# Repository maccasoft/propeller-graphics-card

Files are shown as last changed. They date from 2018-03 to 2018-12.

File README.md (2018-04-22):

## Propeller Graphics Card

Add-on board and firmware designed for the [RC2014](http://rc2014.co.uk/) computer to provide graphics capabilities.

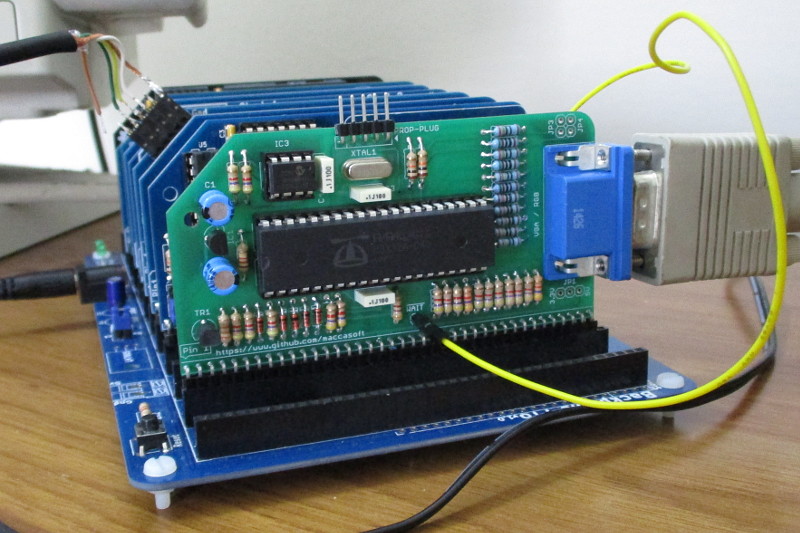
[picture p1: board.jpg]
The board


### Specifications

 * Resolution up to 320x240 pixels with 64 colors
 * Tile graphics with 8x8 pixels tiles
 * Sprites with 8x8 up to 32x32 pixels
 * Full screen scroll
 * Overlays for score and indicators
 * Bitmap graphics modes 320x240x3bpp, 256x192x4bpp and 256x224x4bpp
 * RGB PAL, NTSC and VGA output

The board uses I/O ports **40H, 41H, 42H and 43H** for programming.

See the [Wiki](https://github.com/maccasoft/propeller-graphics-card/wiki) pages for the documentation.

### Schematic

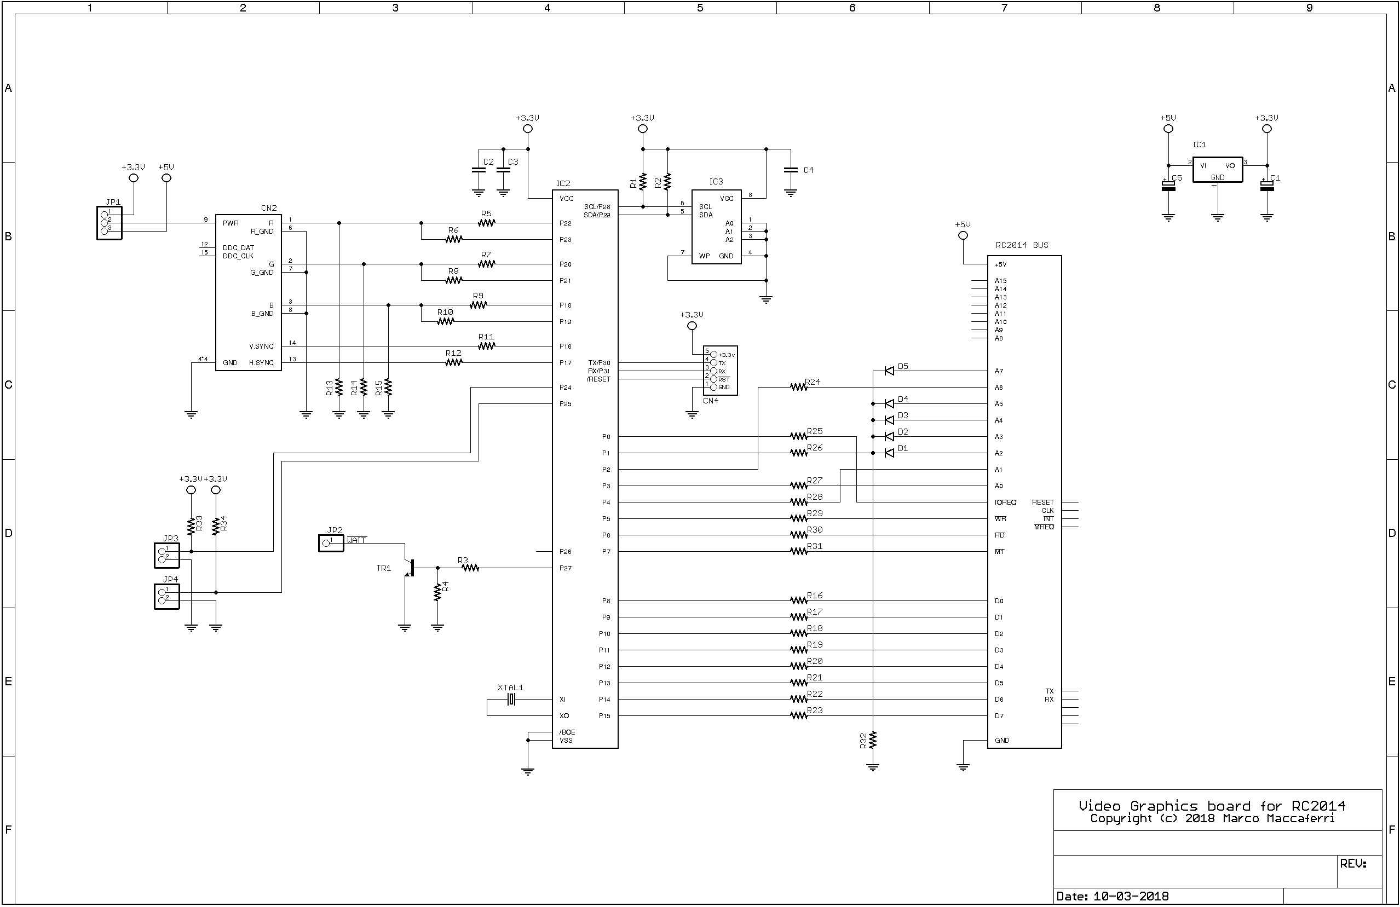
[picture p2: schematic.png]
The schematic


| Parts List | | | |
| --- | --- | --- | --- |
| R1, R2, R16-R31 | 4.700 ohm 1/4 watt  | IC1 | MCP1700-3302E/TO |
| R3 | 1.200 ohm 1/4 watt  | IC2 | P8X32A-D40 |
| R4 | 33.000 ohm 1/4 watt | IC3 | 24LC512 |
| R5, R7, R9 | 510 ohm 1/4 watt 1% | TR1 | NPN Transistor BC547 |
| R6, R8, R10, R11, R12 | 240 ohm 1/4 watt 1% | JP1 | 3 pin male header |
| R13, R14, R15 | 130 ohm 1/4 watt 1% | JP2 | 1 pin male header |
| R32, R33, R34 | 10.000 ohm 1/4 watt | JP3, JP4 | 2 pin male header |
| C1, C5 | 10 uF 63v elettr. | CN1 | 40 pin male header, right angle |
| C2, C3, C4 | 100.000 pF poly. | CN2 | DB15 HD female connector |
| D1, D2, D3, D4, D5 | 1N4148 | CN4 | 5 pin male header |
| XTAL1 | 5 MHz crystal | | |

Board shared on [OSHPark](https://oshpark.com/shared_projects/1gud4wQD) and available on [Tindie](https://www.tindie.com/stores/maccasoft/).

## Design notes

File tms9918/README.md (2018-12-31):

## TMS9918 Emulation Firmware

The TMS9918A was used in the TI-99/4A, MSX, ColecoVision and original Sega SG-1000.
This emulation firmware supports all graphics modes (mode 1, mode 2, multicolor mode) and the 40x24 text mode.

The emulation tries to be compatible with the original chip as much as possible however due to how
the Propeller operates there are some differences:

 * Wait states are automatically added by asserting the WAIT line. Unlike the original chip there is
   no need to add NOP instructions to delay writes.
 * Interrupts are not currently supported. To implement frame synchronization use the Frame flag readed from
   the status register. Alternatively, any OUT instruction to the port 43H will halt the processor until
   the next frame blanking period.
 * Collision flag and 5th sprite number doesn't yet work.
 * Palette colors may appear different compared to the original chip due to the different DAC configurations.
 * Emulation is not cycle perfect. Registers are readed at the beginning of each rendered line, however the
   timings are not comparable with the original chip and graphic tricks may not work as expected.
 * Undocumented modes are not supported.

The firmware maps the board's I/O ports as follows:

 *  **40H** - TMS9918 data port  
 *  **41H** - TMS9918 registers / address setup port  
 *  **42H** - Reserved  
 *  **43H** - Frame synchronization  

See here for a board to use the original chip with the RC2014 computer:  
[https://github.com/jblang/TMS9918A](https://github.com/jblang/TMS9918A)

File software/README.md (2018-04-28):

## Propeller Graphics Card

Utilities and demo programs designed to run from CP/M.

 * **fwupd.com**  
   Firmware update utility.  
   
 * **hscroll.com**  
   Horizontal scroll with music demo.  
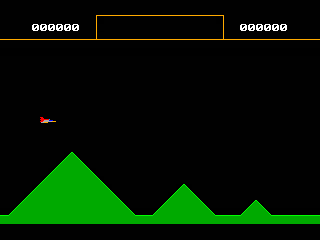
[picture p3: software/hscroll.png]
     
 * **vscroll.com**  
   Vertical scroll with music demo.  
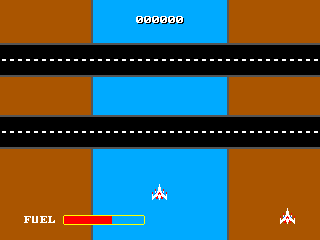
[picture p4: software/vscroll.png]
     
   
 * **bars.com**  
   Colored bars.  
 * **sinwave.com**  
   Simple 3D math function drawing using the Z-buffer algorithm (from z88dk).  
 * **coswave.com**  
   Simple 3D math function drawing using the Z-buffer algorithm (from z88dk).  

All programs can be compiled with [z88dk](https://www.z88dk.org) using the provided Makefile or individually using the instructions in the source files.

### License

Unless otherwise specified all programs are distributed with the GNU GPL-V3 license, images, design files and other artwork
are distributed under the Creative Commons Attribution-ShareAlike 3.0 license.

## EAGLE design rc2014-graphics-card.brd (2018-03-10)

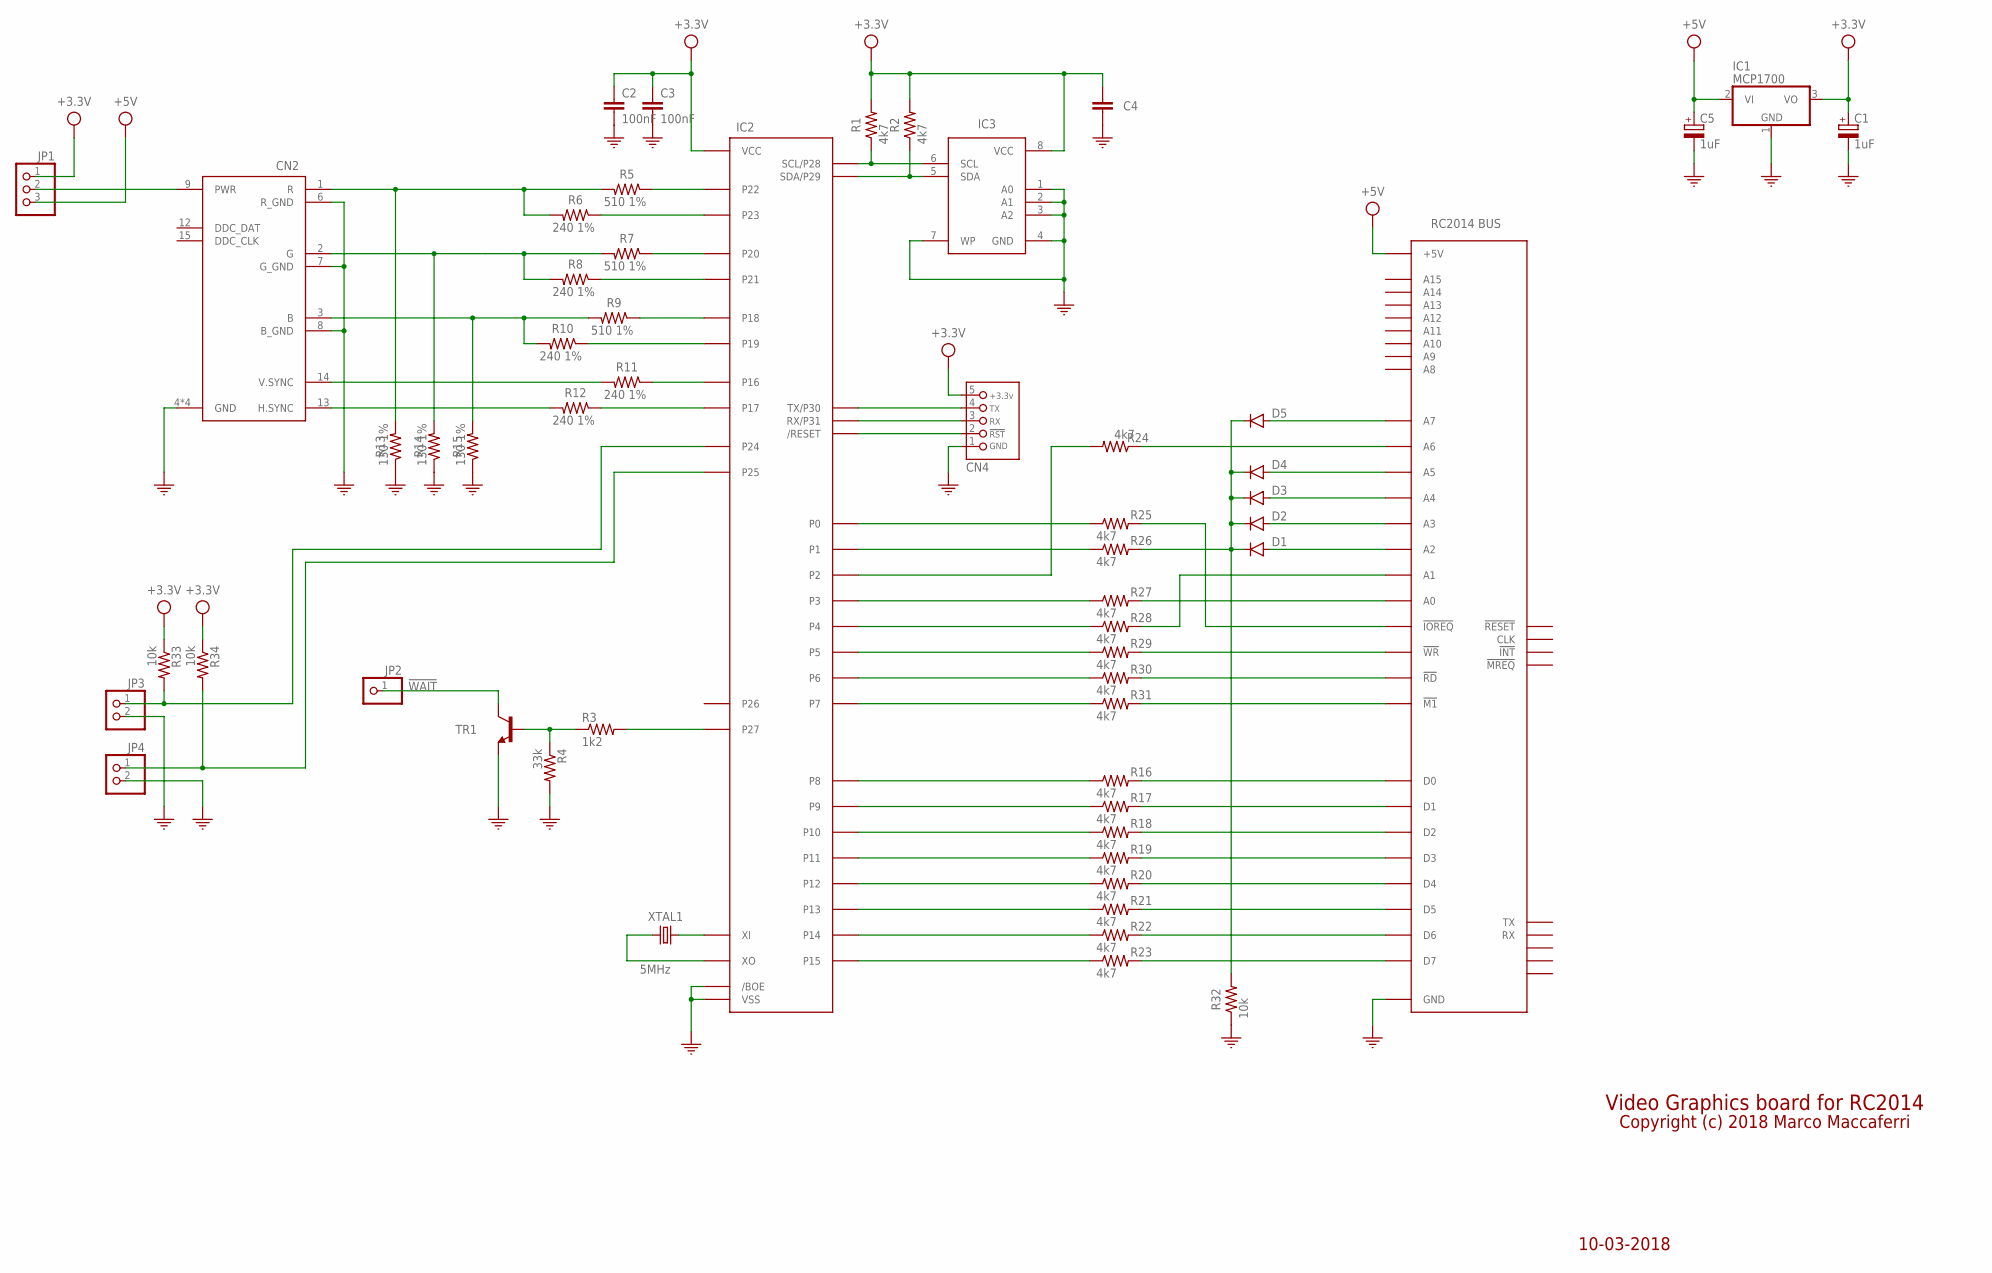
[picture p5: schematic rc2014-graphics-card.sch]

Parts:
C1, C5: 1uF; E2,5-6; MPN ESK105M050AC3AA
C2, C3, C4: 100nF; C050-025X075; MPN R82EC3100AA70J
CN1: RC2014BUS; MPN PRPC040SBAN-M71RC
CN2: VGA; MPN 1734344-1
CN4: PROPELLER_ICSP_HEADER; HEADER_PRG_1X05; MPN PRPC005SAAN-RC
D1, D2, D3, D4, D5: 1N4148DO35-7; DO35-7
IC1: MCP1700; TO92; MPN MCP1700-3302E/TO
IC2: P8X32A-B-D40; DIL40; MPN P8X32A-D40
IC3: 24LC512-I/P; DIL08; MPN 24LC256-I/P
JP1: PINHD-1X3; 1X03
JP2: PINHD-1X1; 1X01
JP3, JP4: PINHD-1X2; 1X02
R1, R2: 4k7; 0207/10; MPN CFR-25JB-52-4K7
R3: 1k2; 0207/10
R4: 33k; 0204/7
R5, R7, R9: 510 1%; 0207/10; MPN RNMF14FTC510R
R6, R8, R10, R11, R12: 240 1%; 0207/10; MPN RNMF14FTC240R
R13, R14, R15: 130 1%; 0207/10; MPN RNMF14FTC130R
R16, R17, R18, R19, R20, R21, R22, R23, R24, R25, R26, R27, R28, R29, R30, R31: 4k7; 0204/7
R32: 10k; 0204/7
R33, R34: 10k; 0207/10
TR1: BC547A; TO92
XTAL1: 5MHz; HC49/S; MPN ECS-50-20-4X

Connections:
!IOREQ!: IC2.1 (P0), R25.1
!M1!: IC2.8 (P7), R31.1
!RD!: IC2.7 (P6), R30.1
!WAIT!: JP2.1, TR1.1 (C)
!WR!: IC2.6 (P5), R29.1
+3.3V: C1.+, C2.1, C3.1, C4.1, CN4.5, IC1.3 (VO), IC2.12 (VCC), IC2.32 (VCC), IC3.8 (VCC), JP1.1, R1.2, R2.2, R33.1, R34.1
+5V: C5.+, CN1.+5V, IC1.2 (VI), JP1.3
A0: IC2.4 (P3), R27.1
A1: IC2.5 (P4), R28.1
A6: IC2.3 (P2), R24.2
ADDR: IC2.2 (P1), R26.1
B: CN2.3 (B), R9.2, R10.2, R15.2
D0: IC2.13 (P8), R16.1
D1: IC2.14 (P9), R17.1
D2: IC2.15 (P10), R18.1
D3: IC2.16 (P11), R19.1
D4: IC2.17 (P12), R20.1
D5: IC2.18 (P13), R21.1
D6: IC2.19 (P14), R22.1
D7: IC2.20 (P15), R23.1
G: CN2.2 (G), R7.2, R8.2, R14.2
GND: C1.-, C2.2, C3.2, C4.2, C5.-, CN1.GND, CN2.4 (GND), CN2.5 (GND), CN2.6 (R_GND), CN2.7 (G_GND), CN2.8 (B_GND), CN2.10 (GND), CN2.11 (GND), CN4.1, IC1.1 (GND), IC2.9 (VSS), IC2.10 (/BOE), IC2.29 (VSS), IC3.1 (A0), IC3.2 (A1), IC3.3 (A2), IC3.4 (GND), IC3.7 (WP), JP3.2, JP4.2, R4.2, R13.1, R14.1, R15.1, R32.1, TR1.3 (E)
GPU_SCL: IC2.37 (SCL/P28), IC3.6 (SCL), R1.1
GPU_SDA: IC2.38 (SDA/P29), IC3.5 (SDA), R2.1
HSYNC: CN2.13 (H.SYNC), R12.2
unnamed: IC2.30 (XI), XTAL1.1
unnamed: IC2.31 (XO), XTAL1.2
unnamed: CN1.D3, R19.2
unnamed: CN1.D2, R18.2
unnamed: CN1.D1, R17.2
unnamed: CN1.D0, R16.2
unnamed: CN1.D4, R20.2
unnamed: CN1.D5, R21.2
unnamed: CN1.D6, R22.2
unnamed: CN1.D7, R23.2
unnamed: CN4.2, IC2.11 (/RESET)
unnamed: CN4.3, IC2.40 (RX/P31)
unnamed: CN4.4, IC2.39 (TX/P30)
unnamed: CN1.A3, D2.A
unnamed: CN1.A4, D3.A
unnamed: CN1.A5, D4.A
unnamed: CN1.A6, R24.1
unnamed: CN1.A7, D5.A
unnamed: D1.C, D2.C, D3.C, D4.C, D5.C, R26.2, R32.2
unnamed: CN1.A2, D1.A
unnamed: CN1.A1, R28.2
unnamed: CN1.A0, R27.2
unnamed: CN1.!RD!, R30.2
unnamed: CN1.!WR!, R29.2
unnamed: CN1.!M1!, R31.2
unnamed: CN1.!IOREQ!, R25.2
unnamed: CN2.9 (PWR), JP1.2
unnamed: R3.1, R4.1, TR1.2 (B)
unnamed: IC2.36 (P27), R3.2
unnamed: IC2.33 (P24), JP3.1, R33.2
unnamed: IC2.34 (P25), JP4.1, R34.2
P16: IC2.21 (P16), R11.1
P17: IC2.22 (P17), R12.1
P18: IC2.23 (P18), R9.1
P19: IC2.24 (P19), R10.1
P20: IC2.25 (P20), R7.1
P21: IC2.26 (P21), R8.1
P22: IC2.27 (P22), R5.1
P23: IC2.28 (P23), R6.1
R: CN2.1 (R), R5.2, R6.2, R13.2
VSYNC: CN2.14 (V.SYNC), R11.2

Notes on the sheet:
RC2014 BUS
Video Graphics board for RC2014
10-03-2018
Copyright (c) 2018 Marco Maccaferri

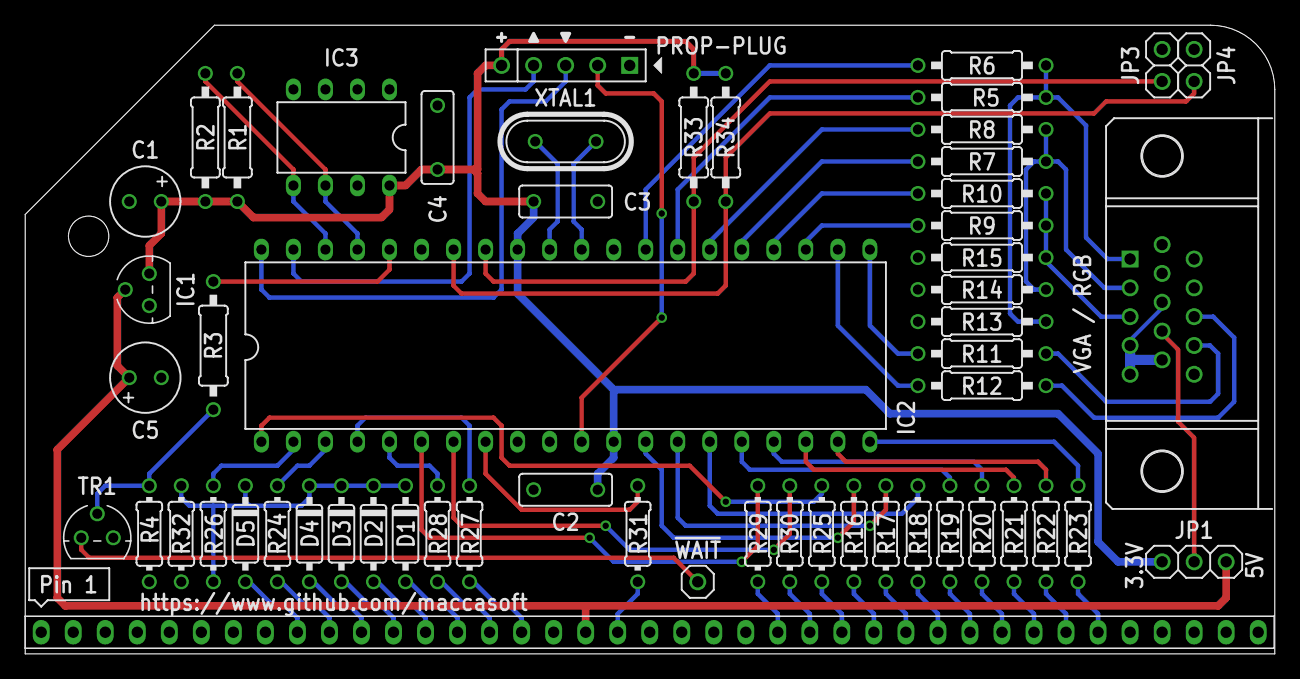
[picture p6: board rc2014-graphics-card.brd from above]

Board: 2 copper layers, 99.1 x 49.9 mm, 56 parts (0 on the bottom side), 66 nets.

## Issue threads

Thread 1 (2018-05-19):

Does it require Backplane Pro or any backplane?

sajattack, 2018-05-19:

maccasoft, 2018-05-19:
The connector is the standard single-row compatible with any backplane, however to have frame synchronization a wire must be connected to the Z80 WAIT line (the yellow cable in the photo) on the extended bus connector, if available, or on the CPU board.

Closed 2018-05-19.

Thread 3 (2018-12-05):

full 9x16 support now available

konimaru, 2018-12-05:
Just to let you know that there is now a new version available which uses a real 9x16 font (liberated from some FON file). The colour blink attribute is currently MIA but can be brought back if necessary.

konimaru, 2018-12-07:
(optional) blink mode is now available again.

maccasoft, 2018-12-07:
Thanks, I'm following your repository and saw the discussion. I haven't yet tested the new driver, will do soon.
Thank you very much for your work!

konimaru, 2018-12-18:
In case you didn't notice, there is now another version using an 8x16 font but with characters $C0-$DF having their 8th column duplicated (like IBM's MDA mode). Will save you 1K of hub RAM. Otherwise it's the same as the **NINE**.

**Also, happy holidays from Lake Constance (the one in Germany) and best wishes for 2019!**

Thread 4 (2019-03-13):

How fast can it go?

cbmeeks, 2019-03-13:
I've wondered about using a Propeller in a SBC that I have created.  My computer runs between 1 and 4 MHz (6502).  I have pushed it to 8 MHz with no issues.

However, I've wondered how the Propeller could keep up at higher speeds?  I imagine RC2014's usually run at 3.5 - 4.0 MHz.

So my question is, how fast have you pushed this card using direct bus access?  When do you think the CPU would have to have wait states before the Propeller can't handle it?

Thanks

maccasoft, 2019-03-13:
The RC2014 standard clock is 7.3728 MHz and there aren't problems with the Propeller. However the Z80 adds a wait state to all I/O operations that helps with the timings.

I haven't run many speed tests, however there are two things to consider:

1. Write operations (OUT instructions). The limit is about the time needed to store the data bus value after the port address condition is met, then you can use the time needed by the processor to read and decode other instructions to do all internal things. I think that the Z80 can be pushed to 10-12 MHz without problems, then it is just a matter of how many things the Propeller needs to do before being ready for the next I/O data. The fastest I/O instruction on the Z80 is OUTI which takes 16 clock cycles, plenty of time to write to the Propeller hub ram.

2. Read operations (IN instructions). This absolutely needs wait states, there is simply not enough time to toggle the port bits so the Z80 can read the correct data. Maybe at 2MHz or less it can work, haven't tried that slow.

The standard firmware for the graphics card uses write-only operations without wait states unless the user wants to change resolution, in that case the wait line is asserted until the Propeller is ready again. The TMS9918 emulation firmware on the other hand always uses wait states because it allows to read and write to the vram.

cbmeeks, 2019-03-13:
Thanks for the response.

The 6502, IIRC, is around 4-7 clock cycles for a write operation.  I guess I just need to do the math.  Right now, I'm running at 1 MHz while I develop.  So probably more than OK there in read or write.

Thanks for your input.

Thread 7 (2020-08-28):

Combine with VT100 functionality

cyrusbuilt, 2020-08-28:
This is really more of a technical question than an "issue":

Looking at the schematics for both the graphics card and the vt100 terminal card, it looks like it would be relatively easy to combine the functionality of both cards into one, at least from an electrical point of view.  Also, if designed to be compatible with the enhanced RC2014 bus or perhaps the unofficial BP-80 bus (such as that used by Stephen Cousins SC126, which is backward-compatible) it could tie the /WAIT pin straight into the bus as opposed to having a separate header pin for it.

But then there is the firmware.  My first thought is you could send a command to switch between graphics mode and terminal mode. The board would start up in terminal mode by default, of course.  Then a game or program that required graphics would send a command to enter graphics mode and before the program exited, it would have to restore terminal mode.

But I have no idea if that is something that is technically possible on the propeller in terms of firmware size or memory usage, etc.

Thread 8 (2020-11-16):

How can i test this board

almajiro, 2020-11-16:
I finished solder this board. so i want to test it.
I burned the firmware to eeprom using tools from P8X Game System download page.

but, the board is doesn't work.
/WAIT signal is going to low immediately.

Then i burned the VT100 Emulator firmware and it works.

What are the possible causes?

Thank you.

maccasoft, 2020-11-16:
Try to load the TMS9918 emulation firmware and run the ASCII.ASM code, this is the only example that doesn't require the WAIT line support.

almajiro, 2020-11-17:
thank you for your reply.

I burned the TMS firmware then I assembled ascii.asm using tasm on dosbox.
and tested with J.B. Langston's z80ctrl board.

but It didn't work.

I'm using 24LC256 instead of 24LC512. Can this be the cause?

maccasoft, 2020-11-17:
I don't know how z80ctrl board works and if it has conflicts with this board, try to use the minimum required standard boards to test these issue, otherwise we can't know where the problem is.
The TMS9918 demo programs are meant to run from the standard monitor at address 5000h, so set the rom to load the standard monitor, upload the hex file produced by the compiler and run with G5000. Remove the WAIT line wire if this causes problems, for the ASCII demo it is not required.
The 24LC256 should work without problems, the current firmware is below the 32k limit.

almajiro, 2020-11-17:
I tested it with the SCM monitor program, but it didn't work. (i changed the .org to 8000 from 5000)

Does the TMS mode firmware output a VGA signal after the power is turned on?

maccasoft, 2020-11-21:
Yes, all firmwares outputs the VGA signal.
Have you checked the board for shorts and bad solders ?

almajiro, 2020-11-23:
I checked the all connection via multimeter.

maccasoft, 2020-11-26:
I have verified the firmware, both the release and the latest source, and both works as expected with the demo code.

If the VT100 emulator firmware works, at least the VGA connections looks working (both boards are using the same pins for VGA output, because of that you should always get a VGA signal from all firmwares), however the similarity stops here. Another difference is that this firmware doesn't display a blinking cursor only a blank screen (monitors should tell you if there is an active signal).

If the wait line is always asserted (and removing the jumper wire allows the Z80 to boot) makes me think that something is wrong with the VGA initialization but I can't think of a reason for that. I have used a stand-alone programmer (TL866) to write the firmware to the eeprom.

Other things to check are the diodes orientation (the black band should be on the upper side, near the Propeller chip), the transistor TR1 should be the correct type and with the correct pin disposition. I can't think of anything else.

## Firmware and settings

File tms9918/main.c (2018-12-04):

/*
 * Propeller Graphics Card for RC2014 Computer
 *
 * Copyright (c) 2018 Marco Maccaferri
 * MIT Licensed
 *
 */

#include <stdint.h>
#include <propeller.h>

extern uint32_t _load_start_cog_uart_driver[];
extern uint32_t _load_start_cog_bus_interface[];

int main()
{
    // starts the bus interface code replacing the current cog
    coginit(cogid(), _load_start_cog_bus_interface, 0);

    return 0;
}

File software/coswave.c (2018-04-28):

/*

	Z88DK base graphics libraries examples
	Simple 3D math function drawing using the Z-buffer algorithm
	
	The picture size is automatically adapted to the target display size
	
	to build:  zcc +<target> <stdio options> -lm -create-app sinwave.c
	
	Examples:
	  zcc +zx -lm -lndos -create-app sinwave.c
	  zcc +aquarius -lm -create-app sinwave.c
	
	$Id: coswave.c,v 1.4 2011-04-01 06:50:45 stefano Exp $

*/

#pragma output noprotectmsdos
#pragma output noredir
#pragma output nogfxglobals

#include <graphics.h>
#include <stdio.h>
#include <math.h>

#define PORTC       0x40
#define PORTD       0x41

#define SETMODE     0x00
#define SETPIX      0x01
#define CLRSCR      0x09
#define WRPAL       0x0B
#define WRBMP       0x0D

#define MODE_320240 0x03
#define MODE_256192 0x04
#define MODE_256224 0x05

#define getmaxx()   255
#define getmaxy()   191

void clg()
{
    outp(PORTC, SETMODE);
    outp(PORTD, MODE_256192);
    outp(PORTD, 0x00);
    outp(PORTD, 0x00);

    outp(PORTC, SETPIX);
}

void plot(int x, int y)
{
    if (x >= 0 && x <= getmaxx() && y >= 0 && y <= getmaxy()) {
        outp(PORTD, y);
        outp(PORTD, x);
        outp(PORTD, 15);
    }
}

void main()
{
    float x,y,incr,yenlarge;
    int z,buf;

	clg();
	incr=2.0/(float)getmaxx();
	yenlarge=(float)getmaxy() / 6.0;

	for (x=-3.0; x<0; x=x+incr)
	{
		buf=255;
		for (y=-3.0; y<3.0; y=y+0.2)
		{
			z = (unsigned char) (float)getmaxy() - (yenlarge * (y + 3.0) + yenlarge * (cos (x*x + y*y)) );

			if (buf>z)
			{
				buf = z;
				plot ( (int) ((float)getmaxx() / 6.0 * (x + 3.0)),  z);
				plot ( (int) ((float)getmaxx() / 6.0 * (3.0 - x)),  z);
			}
		}
	}
}

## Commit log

2018-03-10 Added board image, schematics, gerbers and parts list
    [rc2014-graphics-card.brd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]
2018-03-13 Added schematic
2018-04-08 Fixed i2c bus release
2018-04-10 Added dependencies build for assembler files
2018-04-12 Fixed i2c eeprom writes
2018-12-31 Reset frame flag only when needed
